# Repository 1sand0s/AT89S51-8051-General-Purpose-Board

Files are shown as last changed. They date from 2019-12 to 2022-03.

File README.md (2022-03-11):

# AT89S51 8051 General Purpose Board



<h2> What is it? </h2>
This is a breakout for AT89S51 that I used during my research at UT Austin. The objective was to study the vulnerability of firmware running on the AT89S51 to Electromagnetic (EM) Side-Channel attacks. 

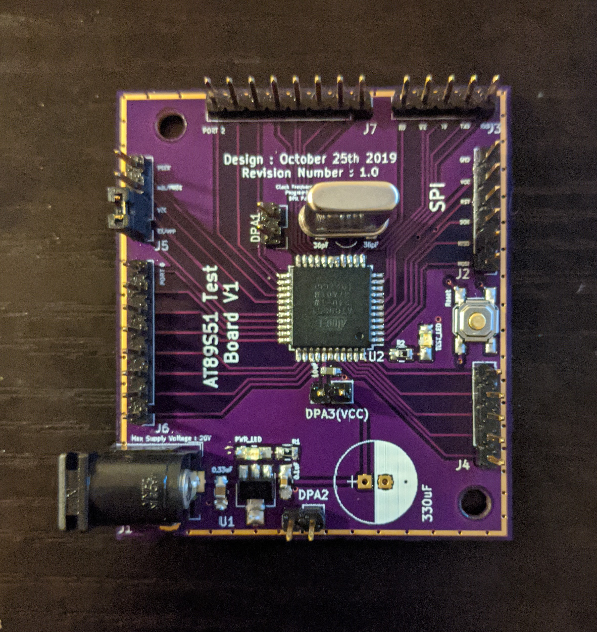
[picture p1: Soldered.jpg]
 

<h2> What we accomplished </h2>

1. We were successful in writing an instruction dissassembler that was able to dissassemble firmware with up to 98% accuracy using the EM side-channel
 
2. We were successful in writing a cycle level EM trace simulator that is capable of synthesizing EM trace corresponding to a firmware running on the AT89S51 with up to 90% accuracy

3. We used the cycle level EM trace simulator to successfully predict control flow leakge of the firmware and optimize it to show a decrease in control flow leakage  
<h2> What the repository contains ? </h2>

The AT89s51 directory contains the board design files. The PCB layouting was done in Kicad. The Bootloader directory contains a powershell script to simplify the usage of avr_dude.exe while burning the HEX file onto the board and the config file describes fuse settings, chip erase details and so on specific to the 8051 to avr_dude.

Please refer to https://1sand0s.github.io/make-your-own-8051at89s51-board.html for more details

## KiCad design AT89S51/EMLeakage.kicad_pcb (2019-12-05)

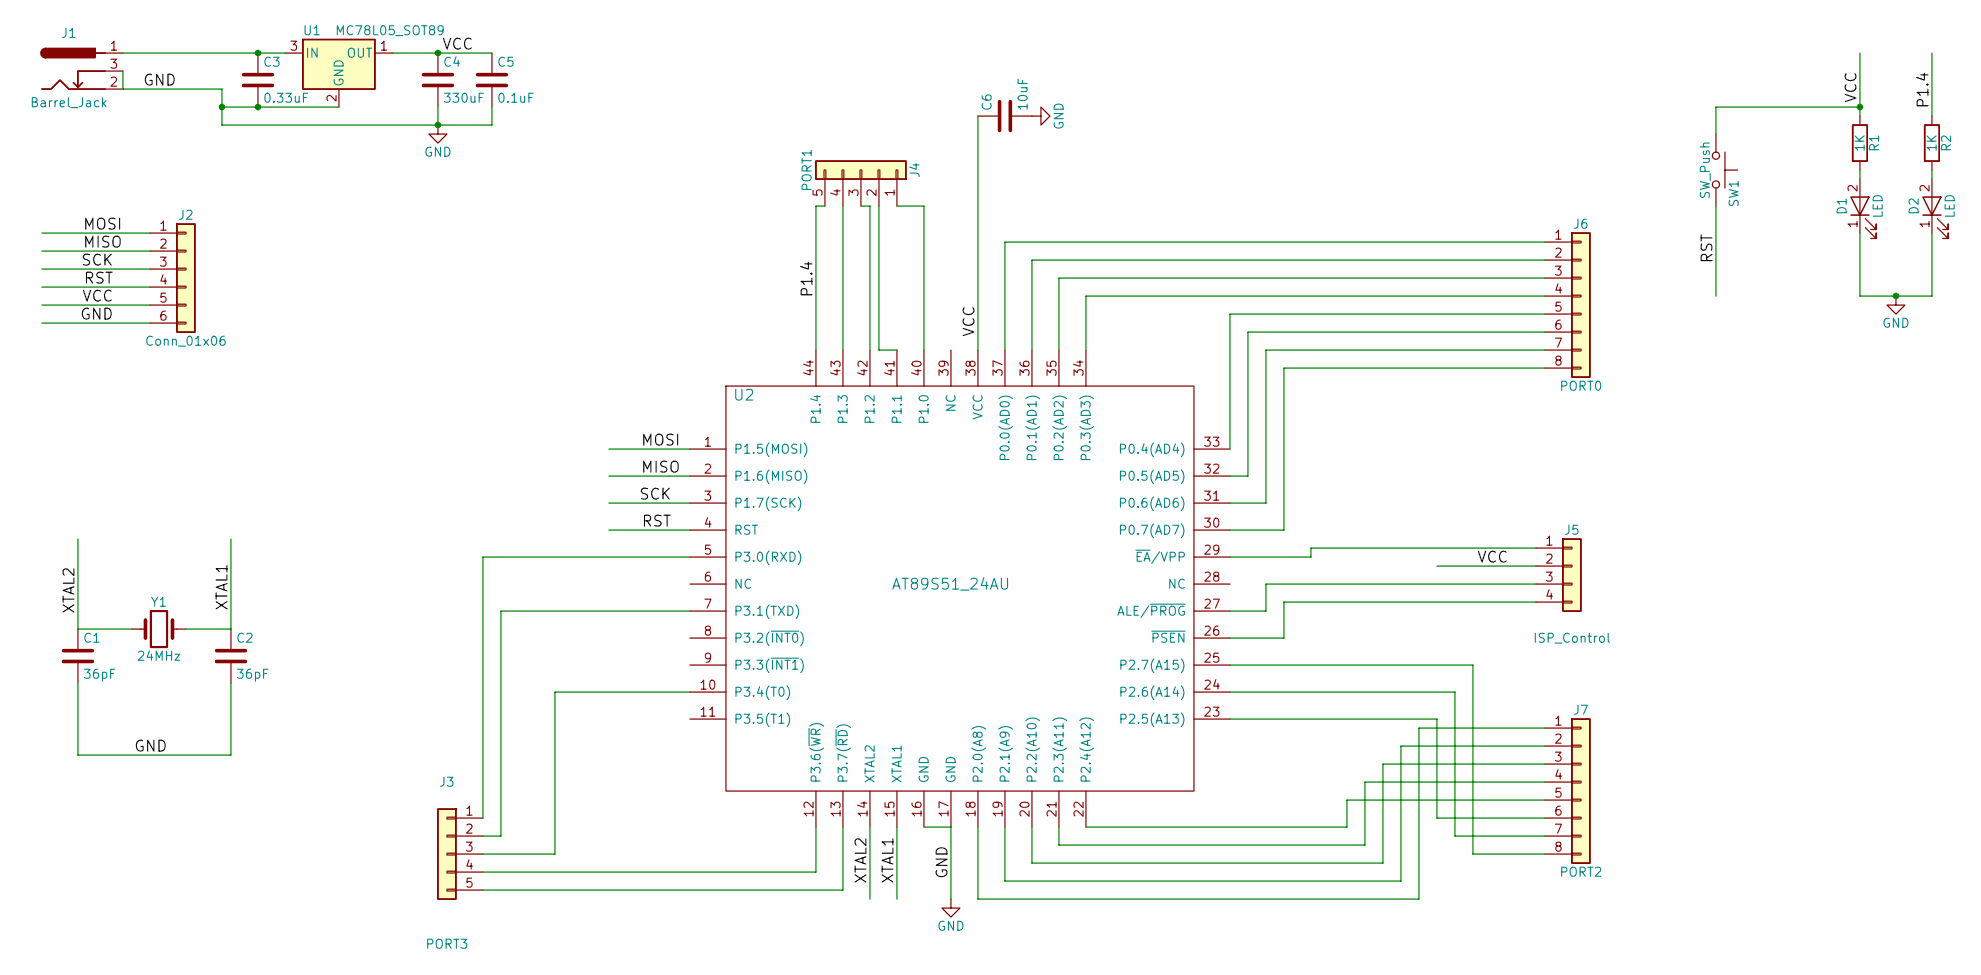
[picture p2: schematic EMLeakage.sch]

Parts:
C1, C2: 36pF; C_0805_HandSoldering
C3: 0.33uF; C_0805_HandSoldering
C4: 330uF; CP_Radial_D10.0mm_P2.50mm
C5: 0.1uF; C_0805_HandSoldering
C6: 10uF; C_0805_HandSoldering
D1, D2: LED; LED_0805_HandSoldering
J1: Barrel_Jack; BARREL_JACK
J2: Conn_01x06; Pin_Header_Straight_1x06_Pitch1.00mm
J3: PORT3; Pin_Header_Straight_1x05_Pitch1.00mm
J4: PORT1; Pin_Header_Straight_1x05_Pitch1.00mm
J5: ISP_Control; Pin_Header_Straight_1x04_Pitch1.00mm
J6: PORT0; Pin_Header_Straight_1x08_Pitch1.00mm
J7: PORT2; Pin_Header_Straight_1x08_Pitch1.00mm
R1, R2: 1K; R_0805
SW1: SW_Push; SW_SPST_SKQG
U1: MC78L05_SOT89; SOT89-3_Housing
U2: AT89S51_24AU; TQFP-44_10x10mm_Pitch0.8mm
Y1: 24MHz; Crystal_AT310_d3.0mm_l10.0mm_Vertical

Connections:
/MISO: J2.2, U2.2 (P1.6(MISO))
/MOSI: J2.1, U2.1 (P1.5(MOSI))
/P1.4: J4.5, R2.1, U2.44 (P1.4)
/RST: J2.4, SW1.2, U2.4 (RST)
/SCK: J2.3, U2.3 (P1.7(SCK))
/VCC: C4.1, C5.1, C6.1, J2.5, J5.2, R1.1, SW1.1, U1.1 (OUT), U2.38 (VCC)
/XTAL1: C2.1, U2.15 (XTAL1), Y1.2
/XTAL2: C1.1, U2.14 (XTAL2), Y1.1
GND: C1.2, C2.2, C3.2, C4.2, C5.2, C6.2, D1.1 (K), D2.1 (K), J1.2, J1.3, J2.6, U1.2 (GND), U2.16 (GND), U2.17 (GND)
unnamed: C3.1, J1.1, U1.3 (IN)
unnamed: D1.2 (A), R1.2
unnamed: D2.2 (A), R2.2
unnamed: J3.1, U2.5 (P3.0(RXD))
unnamed: J3.2, U2.7 (P3.1(TXD))
unnamed: J3.3, U2.10 (P3.4(T0))
unnamed: J3.4, U2.12 (P3.6(~WR))
unnamed: J3.5, U2.13 (P3.7(~RD))
unnamed: J4.1, U2.40 (P1.0)
unnamed: J4.2, U2.41 (P1.1)
unnamed: J4.3, U2.42 (P1.2)
unnamed: J4.4, U2.43 (P1.3)
unnamed: J5.1, U2.29 (~EA~/VPP)
unnamed: J5.3, U2.27 (ALE/~PROG)
unnamed: J5.4, U2.26 (~PSEN)
unnamed: J6.1, U2.37 (P0.0(AD0))
unnamed: J6.2, U2.36 (P0.1(AD1))
unnamed: J6.3, U2.35 (P0.2(AD2))
unnamed: J6.4, U2.34 (P0.3(AD3))
unnamed: J6.5, U2.33 (P0.4(AD4))
unnamed: J6.6, U2.32 (P0.5(AD5))
unnamed: J6.7, U2.31 (P0.6(AD6))
unnamed: J6.8, U2.30 (P0.7(AD7))
unnamed: J7.1, U2.18 (P2.0(A8))
unnamed: J7.2, U2.19 (P2.1(A9))
unnamed: J7.3, U2.20 (P2.2(A10))
unnamed: J7.4, U2.21 (P2.3(A11))
unnamed: J7.5, U2.22 (P2.4(A12))
unnamed: J7.6, U2.23 (P2.5(A13))
unnamed: J7.7, U2.24 (P2.6(A14))
unnamed: J7.8, U2.25 (P2.7(A15))

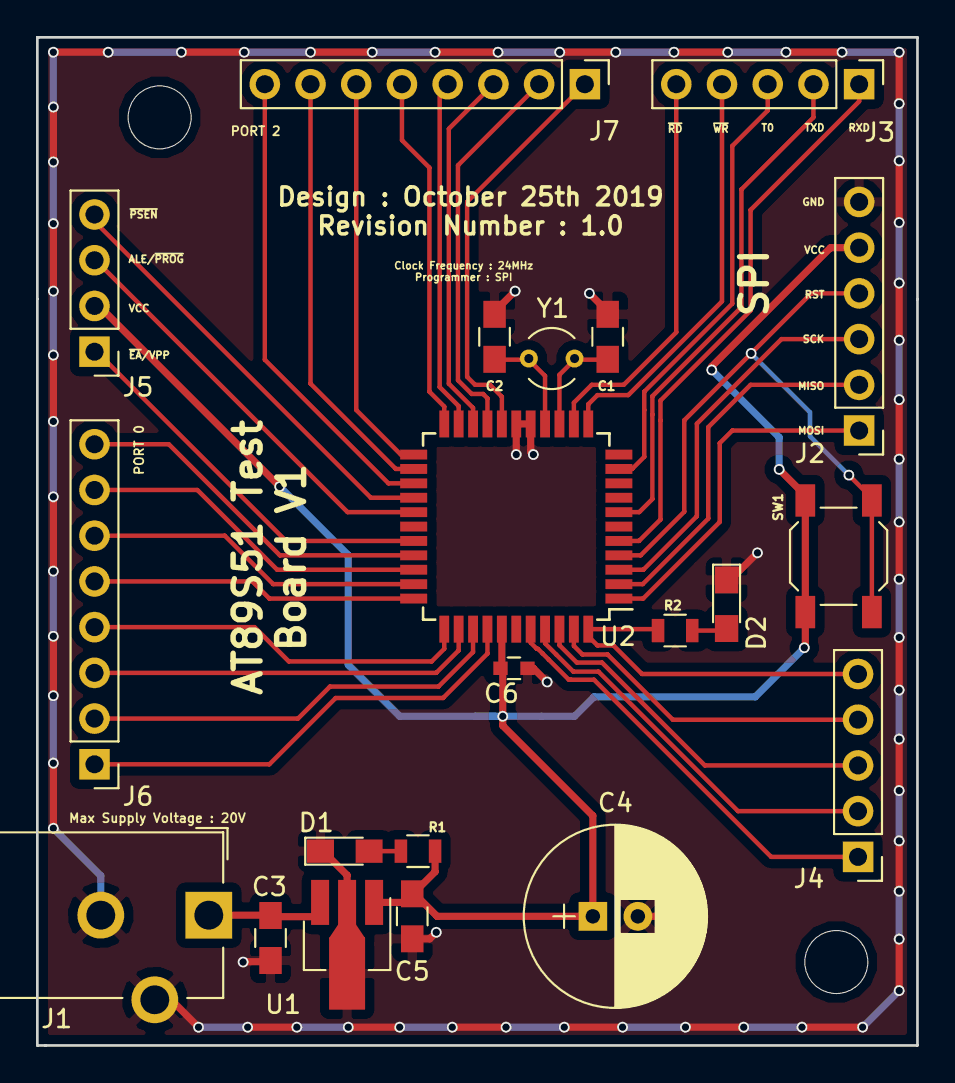
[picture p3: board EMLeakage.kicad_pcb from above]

Board: 2 copper layers, 48.9 x 56.0 mm, 21 parts (0 on the bottom side), 40 nets.

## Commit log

2019-12-05 Adding 8051 Board Kicad Project
    [EMLeakage.kicad_pcb, EMLeakage.sch]
2019-12-05 Uploading the Bootloader script for abstracting avr_dude and simplifying uploading code to the 8051 board
